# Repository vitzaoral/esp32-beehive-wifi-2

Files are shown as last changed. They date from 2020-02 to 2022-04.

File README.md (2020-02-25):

# ESP32 beehive (WiFi version)
Beehives online monitoring based on the ESP32 and others sensors. WiFi version.

> To build a project, you need to download all the necessary libraries and create the *settings.cpp* file in the *src* folder:
```c++
// Project settings
#include "IPAddress.h"

struct Settings
{
    const char *wifiSSID = "YYY";
    const char *wifiPassword = "ZZZ";
    const char *version = "1.0.0";
    const char *firmwareVersionUrl = "http://example.com/version.txt";
    const char *firmwareBinUrl = "http://example.com/firmware.bin";
    IPAddress ip = IPAddress(192, 168, 43, 223);
    IPAddress gateway = IPAddress(192, 168, 43, 1);
    IPAddress subnet = IPAddress(255, 255, 255, 0);
};
```
### Features
* measuring the temperature and humidity inside the hive
* measuring the sound level inside the hive
* triggers an alarm (Blynk notification) when someone opens the hive - a magnetic contact sensor
* triggers an alarm (Blynk notification) when someone picks up the hive - a magnetic contact sensor

### Currents list:

* [ESP32-WROOM-32U](https://www.aliexpress.com/item/4000103411061.html)
* 3x [SHT30 digital temperature/humidity sensor](https://www.aliexpress.com/item/32962846003.html)
* 2x [INA219 sensor](https://www.aliexpress.com/item/32846796535.html)
* 3x [GY-MAX4466 microphone](https://www.aliexpress.com/item/32974988349.html)
* 3x [Magnetic contact sensor](https://www.aliexpress.com/item/32840447389.html)
* [12V MPPT Solar Panel Controller for 18650 Battery](https://www.aliexpress.com/item/32947501783.html)
* 1x - 4x [3.7v 3400 mAh 18650 Lithium battery](https://www.aliexpress.com/item/32807032859.html)
* Solar panel 12V 12W (or 2x [6V 6W panels](https://www.aliexpress.com/item/32901764415.html) in [series](http://sunbeam-bd.blogspot.com/p/blog-page_26.html))
* 3x 9 pins COM cabels and some male/female connectors

### Save battery power:
* Set CPU frequency to 30% (80Mhz) - *setCpuFrequencyMhz(80);*
* Setup lowest WiFi power - *WiFi.setTxPower(WIFI_POWER_MINUS_1dBm);*
* Setup static IP, Gateway and DNS (quicker WiFi connection) - *WiFi.config(settings.ip, settings.gateway, settings.subnet, settings.gateway);*
* When disconnect WiFi, turn off WiFi modem - *WiFi.disconnect(true);*

### Schema:
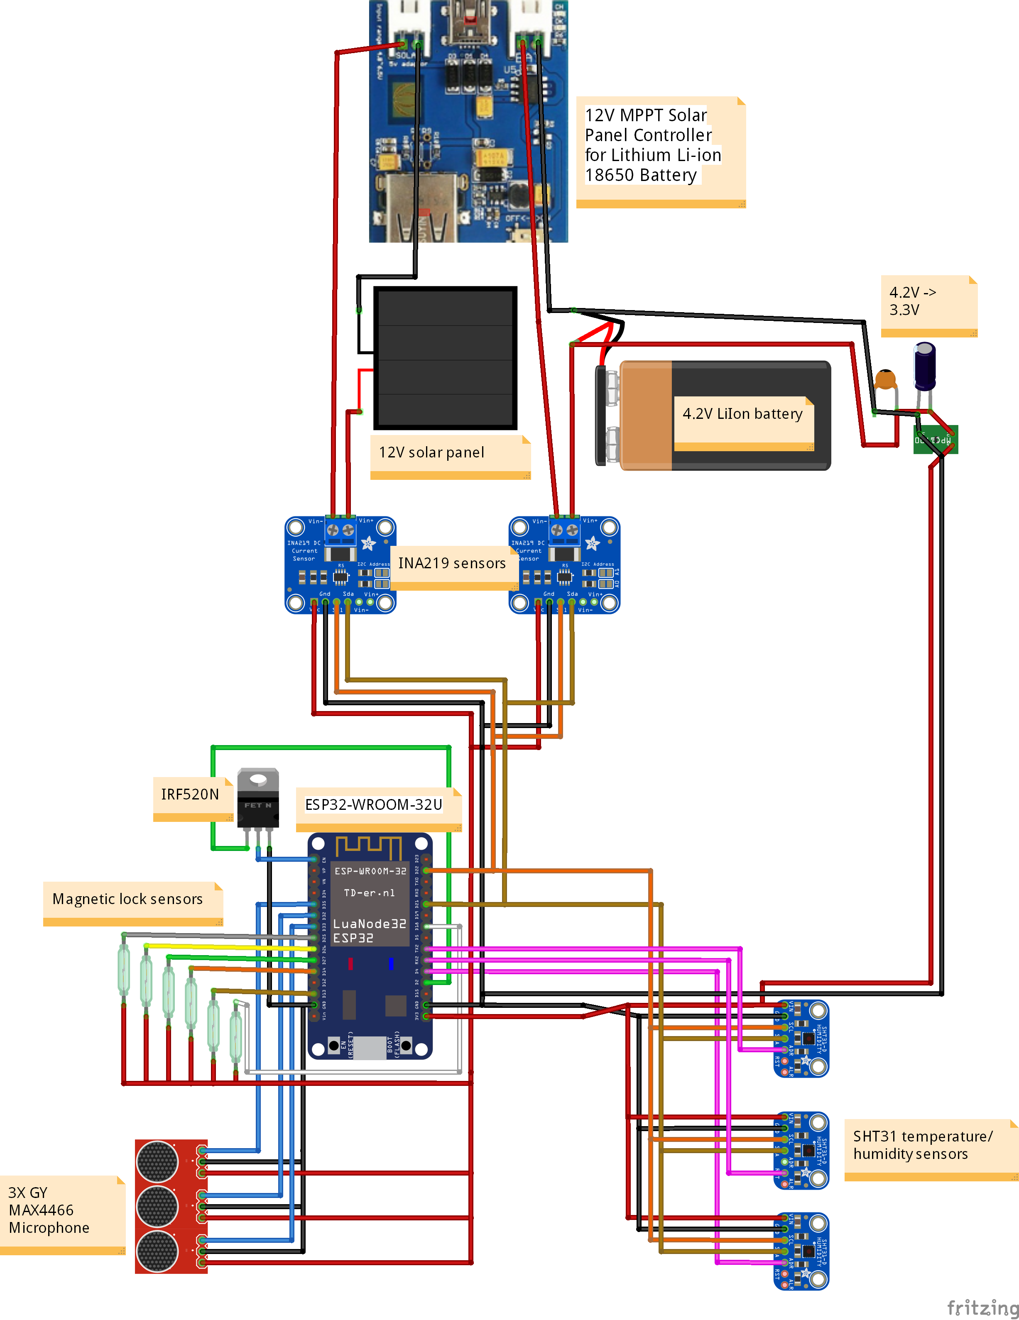
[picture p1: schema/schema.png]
Schema


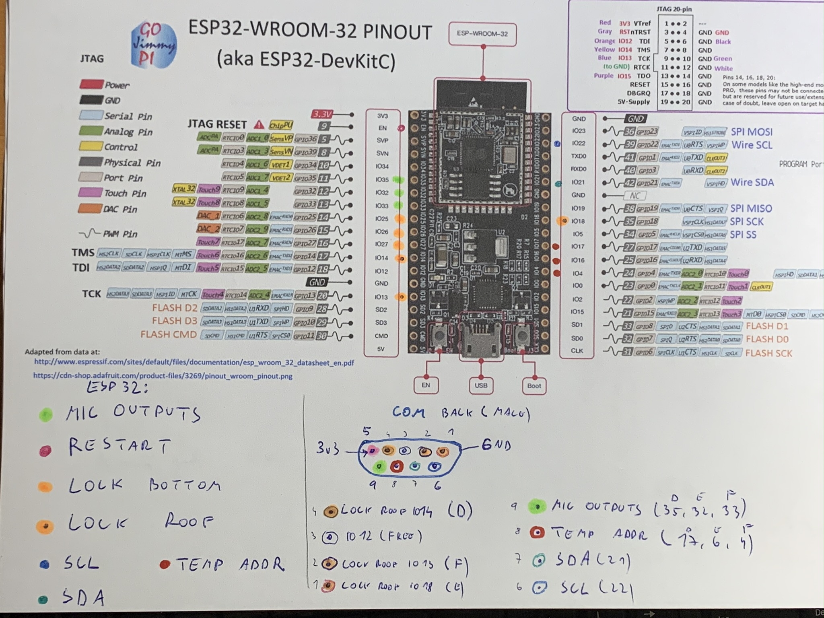
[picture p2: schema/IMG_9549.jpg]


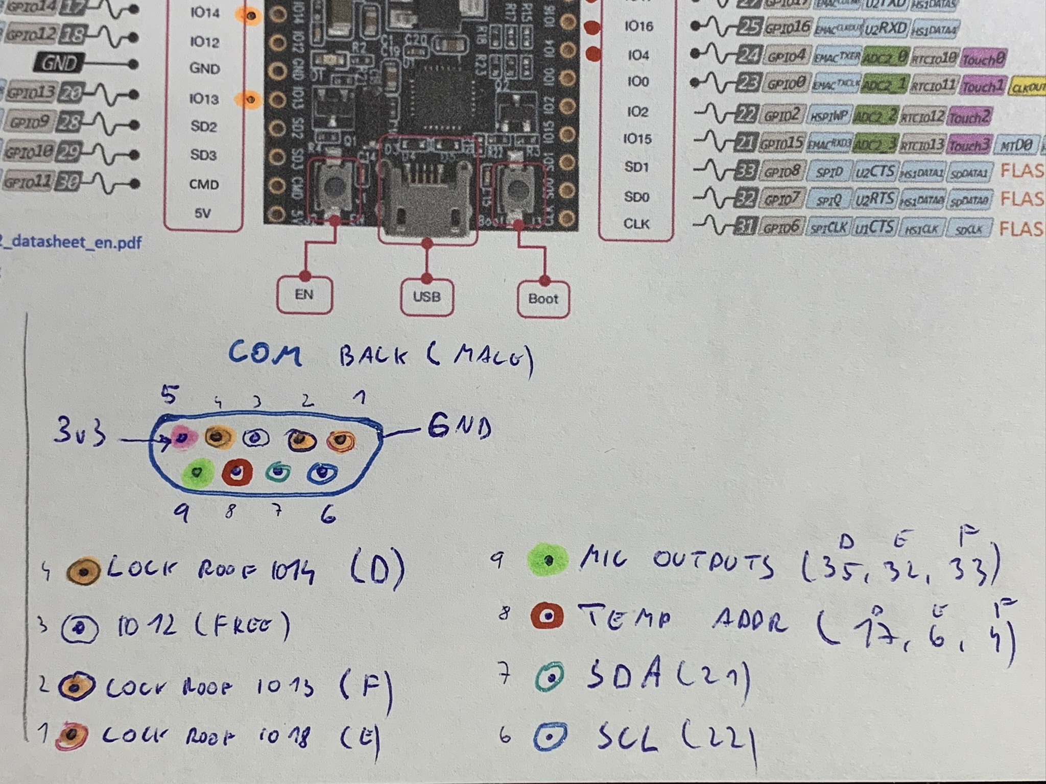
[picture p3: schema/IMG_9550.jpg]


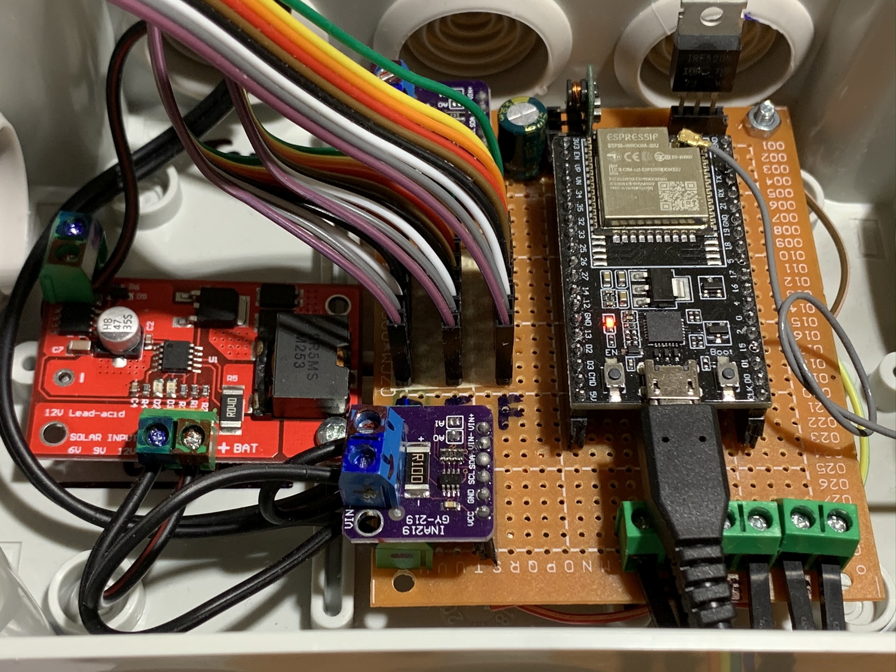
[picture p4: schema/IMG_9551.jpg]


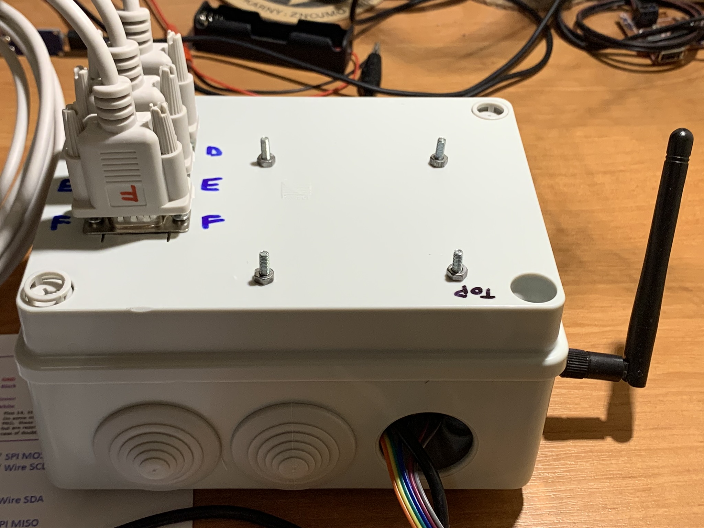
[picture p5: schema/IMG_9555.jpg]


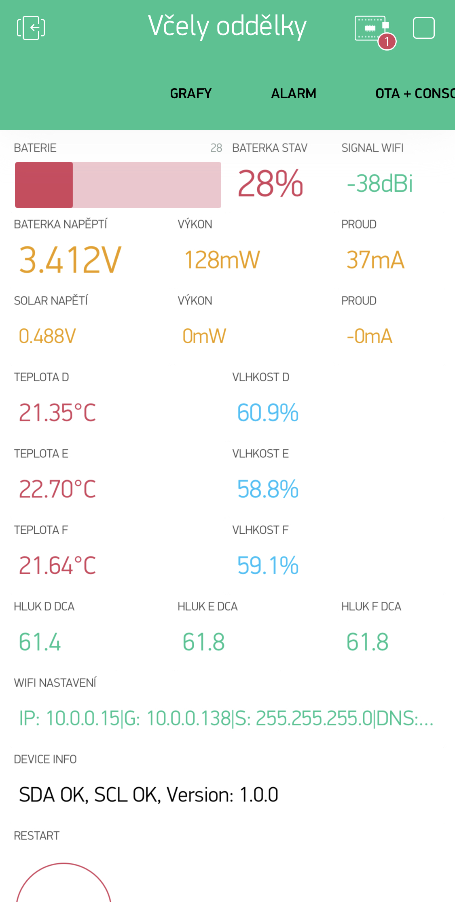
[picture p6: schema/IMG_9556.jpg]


### Powering 5V -> 3.3V:
3v3 regulator - https://randomnerdtutorials.com/esp8266-voltage-regulator-lipo-and-li-ion-batteries/

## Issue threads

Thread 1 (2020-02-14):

Ticker library

mariusrugan, 2020-02-14:
Hi,

I'm trying to setup my development environment for this and for the first version and Ticker library is included from esp32

  Ticker.h - esp32 library that calls functions periodically
  Copyright (c) 2017 Bert Melis. All rights reserved.

which has completely different API than the one you're using.
example:

```
src/main.cpp:34:27: error: 'class Ticker' has no member named 'start'
   timerSendDataToInternet.start();
```

Can you please clarify what lib is used ?

Thanks for your work, i'm trying to achieve the same, a beehive monitoring system on a esp32-cam board. Can't say i'm esp32/C++ expert so please bare with me. :)

vitzaoral, 2020-02-14:
Hi mariusrugan, it seems you have different version of Ticker library. It's true that there are many tickers library and it's little bit confusing. I am using library from [Stefan Staub](https://github.com/sstaub/Ticker). If you are using Visual Studio Code and Platformio, you can easily find this library and install it.

I am working on this project almost every day, so I will post some other updates in next days and weeks...spring is coming 🐝 :)

Good luck with your project :)

Closed 2020-02-19.

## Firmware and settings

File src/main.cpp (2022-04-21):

#include <Arduino.h>
#include <InternetConnection.h>
#include <Ticker.h>
#include "esp32-hal-cpu.h"

InternetConnection connection;
// MeteoData meteoData;
PowerController powerController;
MagneticLockController magneticLockController;
// MicrophoneController microphoneController;

void sendDataToInternet();
void checkMagneticLockAlarm();
void checkMicrophones();

Ticker timerSendDataToInternet(sendDataToInternet, 273000);  // 4.3 min = 260000ms ( + 30sec to microphones, so about 5 minutes to ticker)
Ticker timerMagneticLockAlarm(checkMagneticLockAlarm, 4321); // 4 sec

// alarm section
void sendDataToBlynkIfAlarm();
Ticker timerSendDataToBlynkIfAlarm(sendDataToBlynkIfAlarm, 20000); // 20 sec

void setup()
{
  Serial.begin(115200);

  // save battery, setup lower CPU frequency (default is 240Mhz)
  //setCpuFrequencyMhz(80);
  Serial.println("Get CPU Frequency: " + String(getCpuFrequencyMhz()) + "Mhz");

  timerSendDataToInternet.start();
  timerMagneticLockAlarm.start();
  timerSendDataToBlynkIfAlarm.start();

  // meteoData.initializeSensors();

  // set first data for gyroscope and magnetic locks, other in timers..
  magneticLockController.setData();

  Serial.println("Setup done, send first data");
  sendDataToInternet();
  Serial.println("First data sended, start loop");
}

void loop()
{
  timerSendDataToInternet.update();
  timerMagneticLockAlarm.update();
  timerSendDataToBlynkIfAlarm.update();

  connection.blynkRunIfAlarm();
}

void sendDataToInternet()
{
  Serial.println("Setting sensors data");
  // meteoData.setData();
  powerController.setData();

  if (!connection.isAlarm)
  {
    // takes 30 sec, only without alarm..
    // microphoneController.setData();
  }
  // gyroscope and magnetic locks data are set in other timer more often, so we have actual data

  Serial.println("Start initialize Blynk connection");
  if (connection.initializeConnection())
  {

    Serial.println("Sending data to Blynk");
    connection.sendDataToBlynk(powerController, magneticLockController);
    connection.checkNewVersionAndUpdate();
    connection.disconnect();
  }
  else
  {
    Serial.println("No internet/blynk connection");
    connection.disconnect();
  }
}

void checkMagneticLockAlarm()
{
  magneticLockController.setData();
  if (magneticLockController.isOk())
  {
    // update blynk data and turn alarm off
    if (connection.isAlarm)
    {
      connection.setMagneticLockControllerDataToBlynkIfAlarm(magneticLockController);
    }
    connection.isAlarm = false;
  }
  else
  {
    connection.isAlarm = true;
    connection.alarmMagneticController(magneticLockController);
  }
}

void sendDataToBlynkIfAlarm()
{
  connection.setMagneticLockControllerDataToBlynkIfAlarm(magneticLockController);
}

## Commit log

2020-01-03 Schema, readme
    [schema.fzz]
2020-02-03 Settings, schema
    [schema.fzz]
2020-02-03 Multiple Microphones INMP441 support
    [schema.fzz]
2020-02-17 New schemma
    [schema.fzz]
2020-02-17 Hard reset via mosfet conected to EN pin
2020-02-19 Bug in reset
    [schema.fzz]
2020-02-22 I2S mic are not working on long wires :(
2020-02-22 Instead of I2S MIC use analog MIC
    [schema.fzz]
2020-02-23 Change magnetics roof and microphones pins (can't use ADC2 analog pins and WiFi together)
2020-02-23 Clear "wires memory" for magnetic lockers
2020-02-24 Calibration of microphones
2020-02-25 Microphones are not giving good DB values (battery issue etc)...use just ADC withou DB equations..
2020-02-26 Battery percentage
2020-05-16 F hive roof sensor
2022-04-27 refactor, remove roof sensors
